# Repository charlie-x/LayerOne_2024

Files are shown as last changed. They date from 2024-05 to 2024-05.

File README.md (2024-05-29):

# LayerOne_2024
Repo for LayerOne 2024

# L1 Pov Spinner

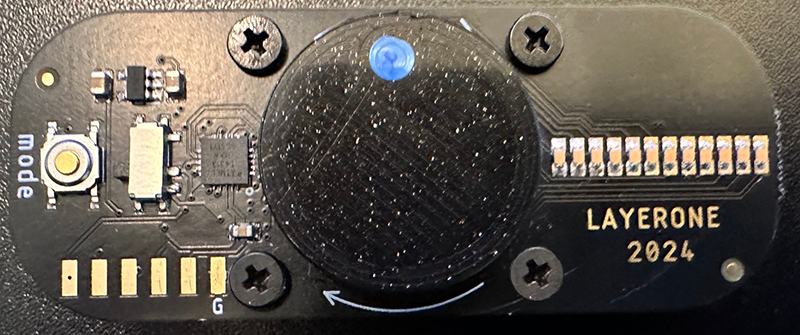
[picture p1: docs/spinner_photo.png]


## What is the Pov Spinner?

The Pov Spinner is an electronic fidget spinner that displays words and patterns via LED's when spinning. It was part of the LayerOne 2024 Conference badge.

## What is needed to change the code on the Spinner?

* Code from repo
* Computer
* AVR programming device
* Build software
* Flash software
* Device drivers

# Code from repo

Clone the git repo or download the zip of the repo

## git clone
```
git clone https://github.com/charlie-x/LayerOne_2024.git
```

## Download zip

```
wget https://github.com/charlie-x/LayerOne_2024/archive/refs/heads/main.zip
```

## Edit the code

Open the **L12024POV.cproj** project file.

The text and animation code is located in **main.c**.

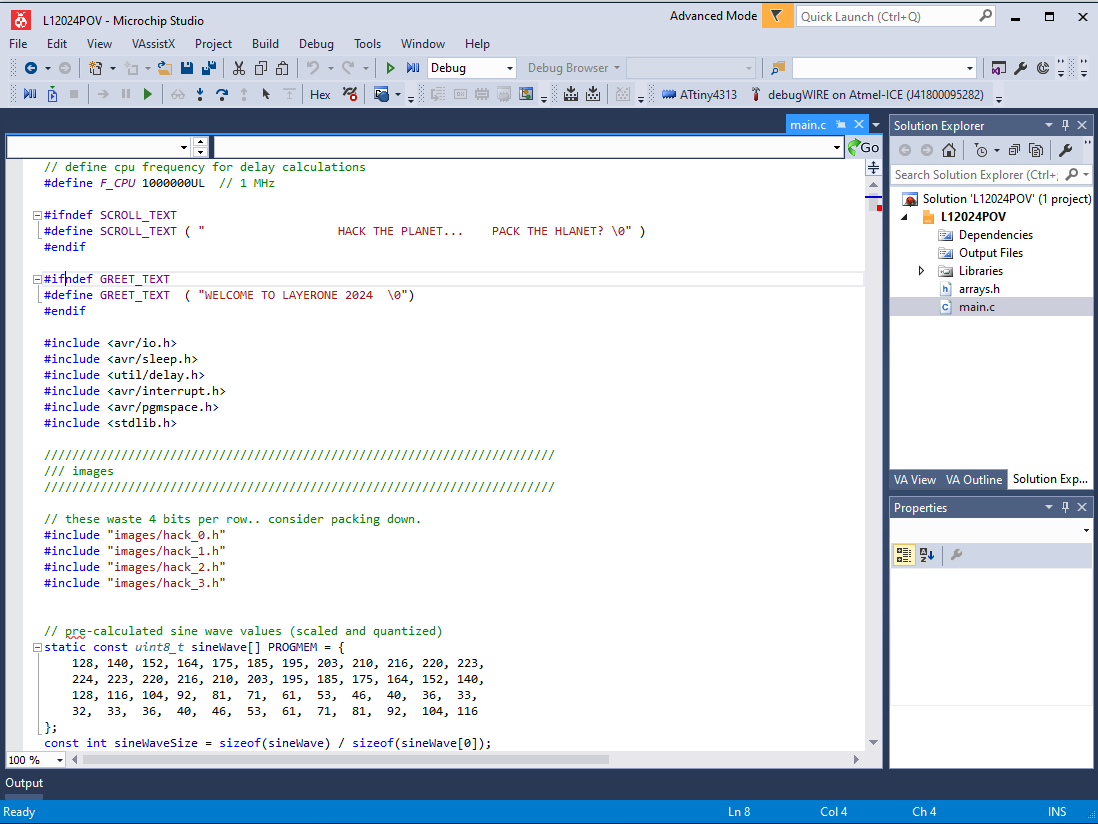
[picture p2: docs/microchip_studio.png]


Once the desired changes are complete, run the **build**. This will output the build files into the **Debug** folder.  

The **L12024POV.hex** file created is what will be used to flash the spinner.

## AVR programing device

**NOTE: Any AVR programmer should work.**

The LayerOne attendees were able to obtain a **Kraken** AVR programmer to use for this purpose which is an avrisp/mkii/avr dragon/usbasp.

Kraken based on this board: 

https://www.fischl.de/usbasp/

### Arduino as an AVR programmer

Alternatively, and Ardunio can be used to program the device:

https://docs.arduino.cc/built-in-examples/arduino-isp/ArduinoISP/

https://www.amazon.com/CANADUINO-USBtinyISP-Programmer-Compatible-Arduino/dp/B0751LJH3Z

## Build Software

Either use Microchip Studio or avr-gcc to build it.

### *nix

Install **avr-gcc** via the **gcc-avr** package

sudo apt-get install binutils gcc-avr avr-libc uisp avrdude flex byacc bison

### Windows

https://www.microchip.com/en-us/tools-resources/develop/microchip-studio

### Mac

port

https://ports.macports.org/port/avr-gcc/

homebrew

https://github.com/osx-cross/homebrew-avr

for avr-gcc's use the makefile

## Flashing the board

**NOTE: The kraken needs avrdude, it is not supported in microchip studio.**

### *nix / Windows / Mac - avrdude

AVRDUDE - is a program for downloading and uploading the on-chip memories of Microchip’s AVR microcontrollers.

Flash the board with the compiled **hex** file to device

https://github.com/avrdudes/avrdude/releases

```
avrdude -c usbasp -p t4313 -v -B 3 -U flash:w:..\LayerOne_2024-main\LayerOne_2024-main\L1_POVSpinner\L12024POV\Debug\L12024POV.hex
```

### Windows - atprogram

atprogram - is a program that comes with Microchip Studio

```
atprogram -cl 200khz -v -d attiny4313 -t atmelice -i isp chiperase
atprogram -cl 200khz -v -d attiny4313 -t atmelice -i isp program -f L12024POV\Release\L12024POV.elf
```

#### Device Drivers for Windows

Zadig is a Windows application that installs generic USB drivers, such as WinUSB, libusb-win32/libusb0.sys or libusbK, to help you access USB devices that can be found here:
https://zadig.akeo.ie/#

Install the **libusbK** driver

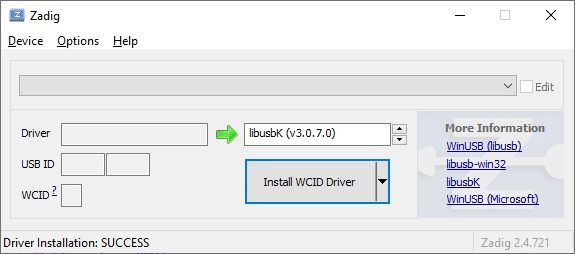
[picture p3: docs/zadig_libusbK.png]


## Spinner Pinouts for programming

The device has the Ground pin labeld as **G**. 

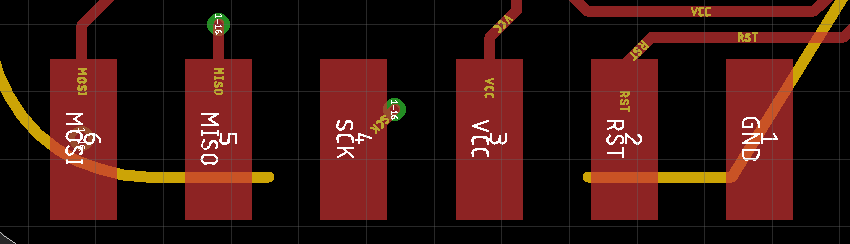
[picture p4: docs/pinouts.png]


## Notes on modifiying the code

The image folder are made of 12xN high 1 bit png's and the imageConvert tool spits them out as a header file, just include them and use drawImage

imageConvert <in.png> <out.h> <label>

use <label> to pass into drawImage use #include <out.h> (with the right name) in the main.c

interrupt driven from a hall effect sensor, triggers the loops to draw and calcs an RPM then it goes into sleep after the effect is drawn, the hall effect can wake it up, but to save battery pressing the button wakes the cpu up again

the slider switch needs to be be in the furthest away position from the programming pads, match the G to gnd on the programmer..

==============================================================================

calculate x/y

30 is 360/nuber of leds around, which is speed dependant  so used the number of leds vertically

  angle_radians = ( led_number * 30 *pi / 180  )

  x_inner = radius * cos ( angle_radius )
  y_inner = radius * cos ( angle_radius )

distance...

  distance = sqrt( (dx^2) + (dy^2))

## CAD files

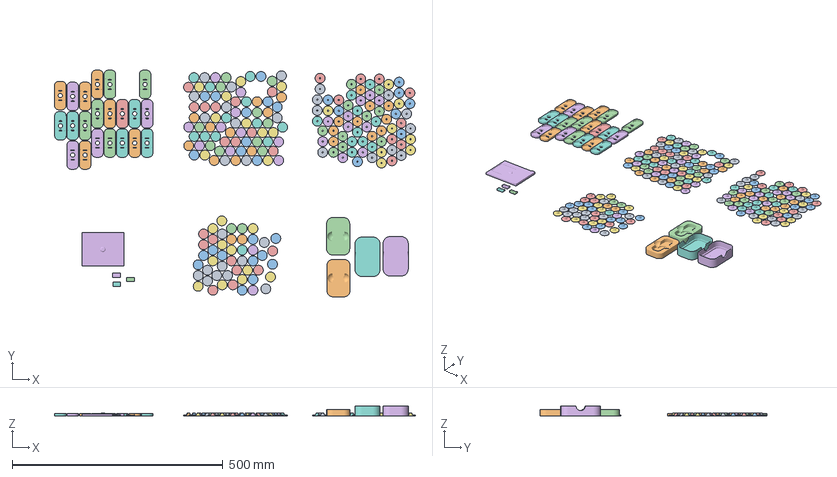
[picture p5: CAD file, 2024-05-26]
L1_2024_PROD_Spinner_Sparkle.3mf
856.6 x 537.8 x 24.2 mm
spin_pov_case_LAYERONE v11 bottom.step
L1_spin_carry_case v3 bottom.step x 2
spin_mag_L1 v8 LOGO.step x 48
spin_pov_case_LAYERONE v11 bottom.step 1
L1_spin_carry_case v4 top.step x 2
spin_pov_case_LAYERONE v11 bottom.step 2
spin_pov_case_LAYERONE v11 bottom.step 3
spin_pov_case_LAYERONE v11 bottom.step 4
spin_pov_case_LAYERONE v11 bottom.step 5
spin_pov_case_LAYERONE v11 bottom.step 6
spin_pov_case_LAYERONE v11 bottom.step 7
spin_pov_case_LAYERONE v11 25.step
spin_pov_case_LAYERONE v11 bottom.step 8
spin_pov_case_LAYERONE v11 bottom.step 9
spin_pov_case_LAYERONE v11 bottom.step 10
spin_pov_case_LAYERONE v11 bottom.step 11
spin_pov_case_LAYERONE v11 bottom.step 12
spin_pov_case_LAYERONE v11 bottom.step 13
spin_pov_case_LAYERONE v11 bottom.step 14
spin_pov_case_LAYERONE v11 bottom.step 15
spin_pov_case_LAYERONE v11 bottom.step 16
spin_pov_case_LAYERONE v11 bottom.step 17
spin_pov_case_LAYERONE v11 bottom.step 18
spin_pov_case_LAYERONE v11 bottom.step 19
spin_pov_case_LAYERONE v11 bottom.step 20
spin_pov_case_LAYERONE v11 bottom.step 21
spin_pov_case_LAYERONE v11 bottom.step 22
spin_pov_case_LAYERONE v11 bottom.step 23
spin_pov_case_LAYERONE v11 bottom.step 24
spin_pov_case_LAYERONE v11 bottom.step 25
spin_pov_case_LAYERONE v11 bottom.step 26
spin_pov_case_LAYERONE v11 bottom.step 27
spin_pov_case_LAYERONE v11 bottom.step 28
spin_pov_case_LAYERONE v11 bottom.step 29
spin_pov_case_LAYERONE v11 bottom.step 30
spin_pov_case_LAYERONE v11 bottom.step 31
spin_pov_case_LAYERONE v11 bottom.step 32
spin_pov_case_LAYERONE v11 bottom.step 33
spin_pov_case_LAYERONE v11 bottom.step 34
spin_pov_case_LAYERONE v11 bottom.step 35
spin_pov_case_LAYERONE v11 bottom.step 36
spin_pov_case_LAYERONE v11 bottom.step 37
spin_pov_case_LAYERONE v11 bottom.step 38
spin_pov_case_LAYERONE v11 bottom.step 39
spin_pov_case_LAYERONE v11 bottom.step 40
spin_pov_case_LAYERONE v11 bottom.step 41
spin_pov_case_LAYERONE v11 bottom.step 42
spin_pov_case_LAYERONE v11 bottom.step 43
spin_pov_case_LAYERONE v11 bottom.step 44
spin_pov_case_LAYERONE v11 bottom.step 45
spin_pov_case_LAYERONE v11 bottom.step 46
spin_pov_case_LAYERONE v11 bottom.step 47
spin_pov_case_LAYERONE v11 bottom.step 48
spin_pov_case_LAYERONE v11 bottom.step 49
spin_pov_case_LAYERONE v11 25.step 1
spin_pov_case_LAYERONE v11 bottom.step 50
spin_pov_case_LAYERONE v11 25.step 2
spin_pov_case_LAYERONE v11 bottom.step 51
spin_pov_case_LAYERONE v11 25.step 3
spin_pov_case_LAYERONE v11 bottom.step 52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

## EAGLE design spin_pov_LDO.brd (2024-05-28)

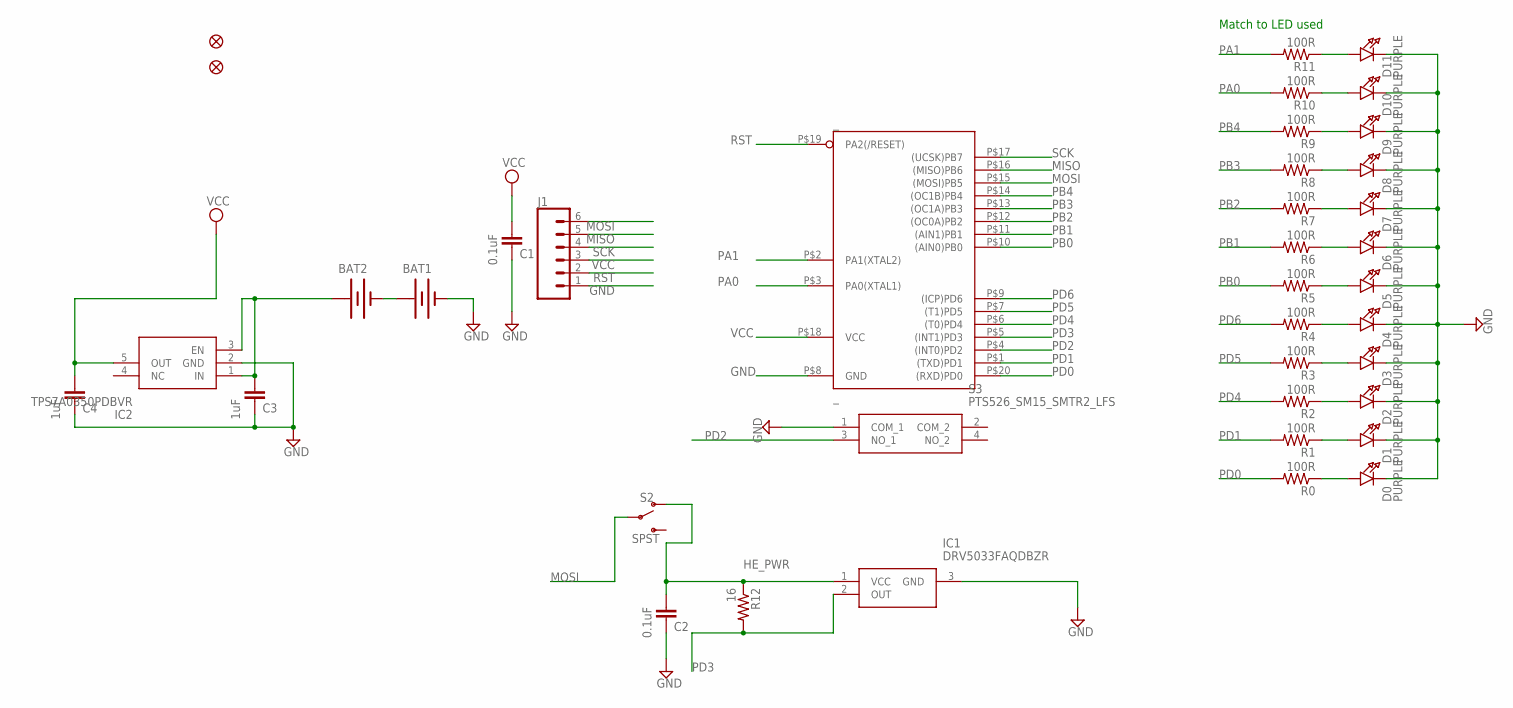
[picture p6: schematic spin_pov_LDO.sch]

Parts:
AFID1, AFID2: FIDUCIAL""; FIDUCIAL_1MM
BAT1, BAT2: SPARKFUN_BATTERYSPARKFUN_BATTCOMM_20MM_LINX; SPARKFUN_BATTCOM_20MM_LINX
C1, C2: 0.1uF; 0805
C3, C4: 1uF; 0805
D0, D1, D2, D3, D4, D5, D6, D7, D8, D9, D10, D11: PURPLE; CHIPLED_0805_NOOUTLINE
IC1: DRV5033FAQDBZR; SOT95P237X112-3N
IC2: TPS7A0350PDBVR; SOT95P280X145-5N
J1: CONN_06SMD-FEMALE-V2; 1X06-SMD-FEMALE
R0, R1, R2, R3, R4, R5, R6, R7, R8, R9, R10, R11: 100R; 0805
R12: 16; 0805
S2: SPST; SWITCH_SPST_SMD_A
S3: PTS526_SM15_SMTR2_LFS; PTS526SM15SMTR2LFS
_: _; MLF20

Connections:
GND: BAT1.2 (-), C1.2, C2.2, C3.2, C4.2, D0.C, D1.C, D2.C, D3.C, D4.C, D5.C, D6.C, D7.C, D8.C, D9.C, D10.C, D11.C, IC1.3 (GND), IC2.2 (GND), J1.1, S3.1 (COM_1), _.P$8 (GND)
HE_PWR: C2.1, IC1.1 (VCC), R12.1, S2.1 (O)
MISO: J1.5, _.P$16 ((MISO)PB6)
MOSI: J1.6, S2.2, _.P$15 ((MOSI)PB5)
unnamed: BAT2.1 (+), C3.1, IC2.1 (IN), IC2.3 (EN)
unnamed: BAT1.1 (+), BAT2.2 (-)
unnamed: D0.A, R0.1
unnamed: D1.A, R1.1
unnamed: D2.A, R2.1
unnamed: D3.A, R3.1
unnamed: D4.A, R4.1
unnamed: D5.A, R5.1
unnamed: D6.A, R6.1
unnamed: D7.A, R7.1
unnamed: D8.A, R8.1
unnamed: D9.A, R9.1
unnamed: D10.A, R10.1
unnamed: D11.A, R11.1
PA0: R10.2, _.P$3 (PA0(XTAL1))
PA1: R11.2, _.P$2 (PA1(XTAL2))
PB0: R5.2, _.P$10 ((AIN0)PB0)
PB1: R6.2, _.P$11 ((AIN1)PB1)
PB2: R7.2, _.P$12 ((OC0A)PB2)
PB3: R8.2, _.P$13 ((OC1A)PB3)
PB4: R9.2, _.P$14 ((OC1B)PB4)
PD0: R0.2, _.P$20 ((RXD)PD0)
PD1: R1.2, _.P$1 ((TXD)PD1)
PD2: S3.3 (NO_1), _.P$4 ((INT0)PD2)
PD3: IC1.2 (OUT), R12.2, _.P$5 ((INT1)PD3)
PD4: R2.2, _.P$6 ((T0)PD4)
PD5: R3.2, _.P$7 ((T1)PD5)
PD6: R4.2, _.P$9 ((ICP)PD6)
RST: J1.2, _.P$19 (PA2(/RESET))
SCK: J1.4, _.P$17 ((UCSK)PB7)
VCC: C1.1, C4.1, IC2.5 (OUT), J1.3, _.P$18 (VCC)

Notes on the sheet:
Match to LED used

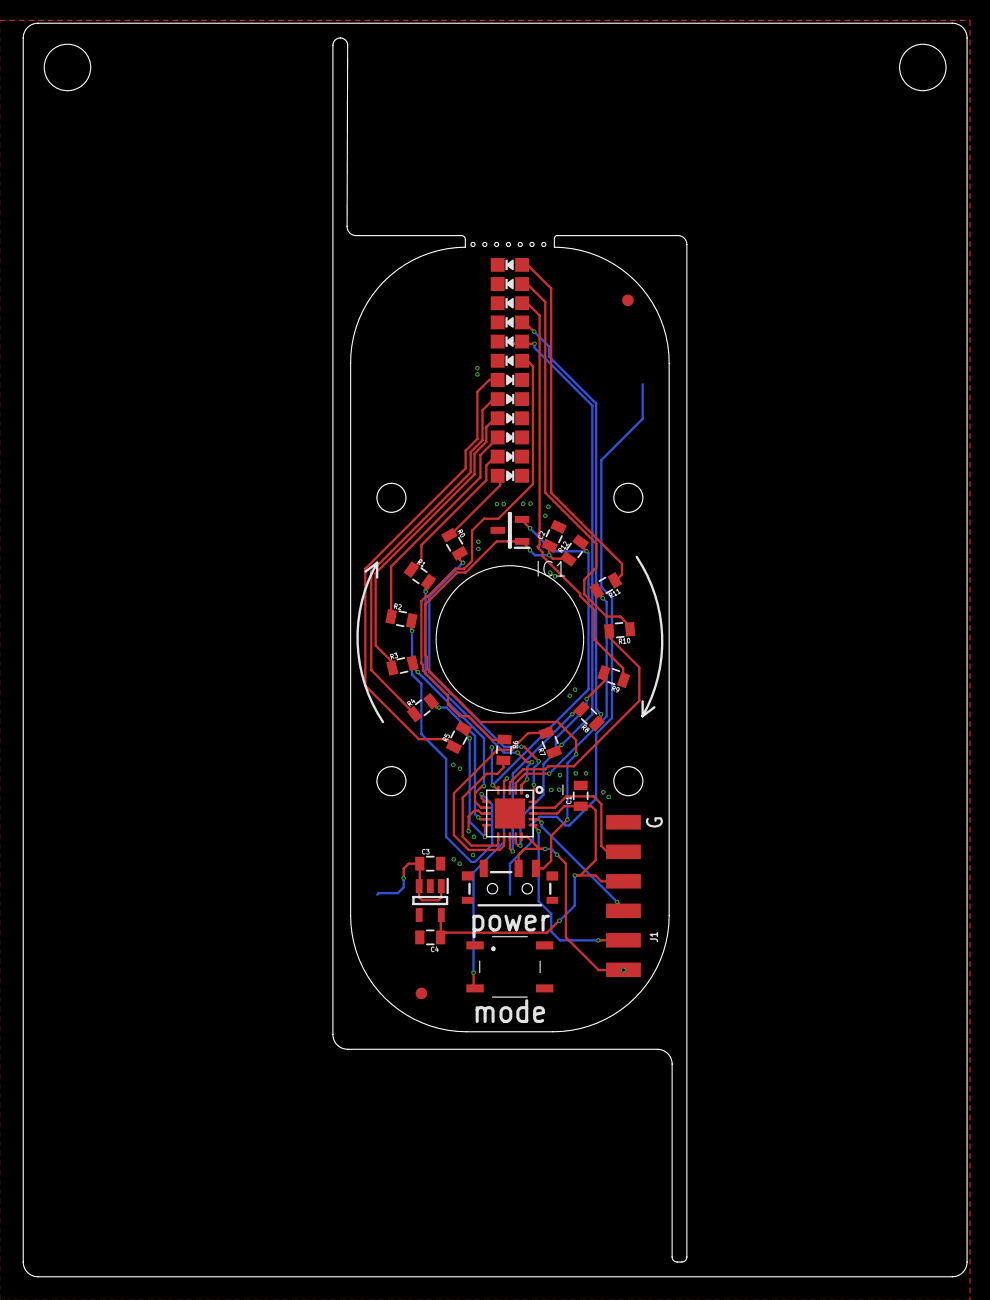
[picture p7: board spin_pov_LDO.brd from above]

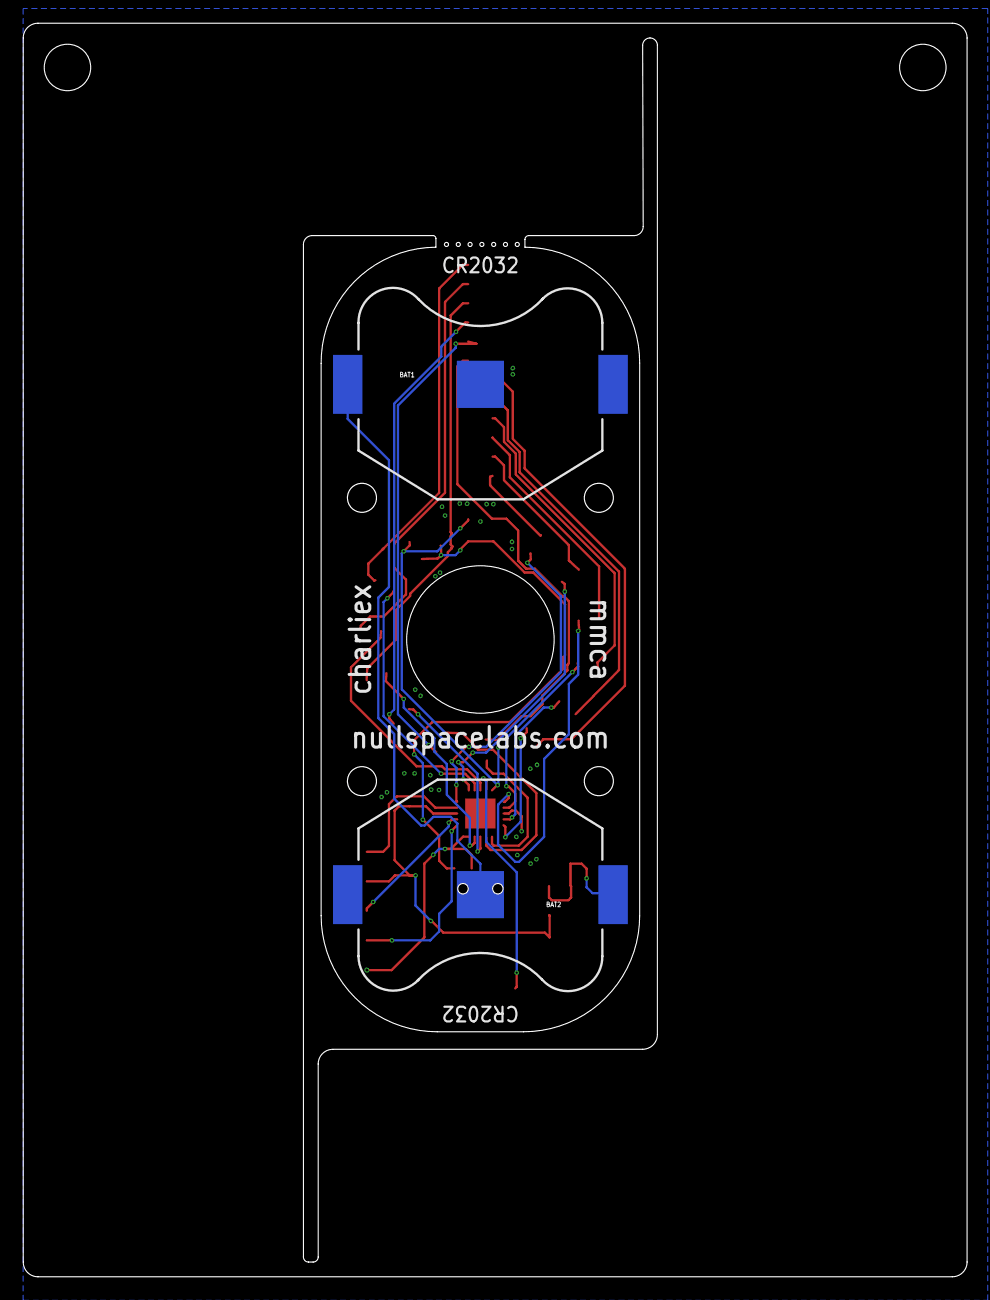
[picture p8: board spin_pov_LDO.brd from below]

Board: 2 copper layers, 81.3 x 107.9 mm, 39 parts (2 on the bottom side), 35 nets.

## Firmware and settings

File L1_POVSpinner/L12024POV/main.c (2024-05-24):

// define cpu frequency for delay calculations
#define F_CPU 1000000UL  // 1 MHz

#ifndef SCROLL_TEXT
#define SCROLL_TEXT ( "                   HACK THE PLANET...    PACK THE HLANET? \0" )
#endif

#ifndef GREET_TEXT
#define GREET_TEXT  ( "WELCOME TO LAYERONE 2024  \0")
#endif

#include <avr/io.h>
#include <avr/sleep.h>
#include <util/delay.h>
#include <avr/interrupt.h>
#include <avr/pgmspace.h>
#include <stdlib.h>

/////////////////////////////////////////////////////////////////////////
/// images
/////////////////////////////////////////////////////////////////////////

// these waste 4 bits per row.. consider packing down.
#include "images/hack_0.h"
#include "images/hack_1.h"
#include "images/hack_2.h"
#include "images/hack_3.h"


// pre-calculated sine wave values (scaled and quantized)
static const uint8_t sineWave[] PROGMEM = {
	128, 140, 152, 164, 175, 185, 195, 203, 210, 216, 220, 223,
	224, 223, 220, 216, 210, 203, 195, 185, 175, 164, 152, 140,
	128, 116, 104, 92,  81,  71,  61,  53,  46,  40,  36,  33,
	32,  33,  36,  40,  46,  53,  61,  71,  81,  92,  104, 116
};
const int sineWaveSize = sizeof(sineWave) / sizeof(sineWave[0]);

/////////////////////////////////////////////////////////////////////////
/// fonts
/////////////////////////////////////////////////////////////////////////


static const uint8_t fontMap[][8] PROGMEM = {

	// Numbers 0-9
	{
		0b00111110, 0b01010001, 0b01001001, 0b01000101, 0b00111110, 0b00000000, 0b00000000, 0b00000000
	}, // 0
	{
		0b00000000, 0b01000010, 0b01111111, 0b01000000, 0b00000000, 0b00000000, 0b00000000, 0b00000000
	}, // 1
	{
		0b01000010, 0b01100001, 0b01010001, 0b01001001, 0b01000110, 0b00000000, 0b00000000, 0b00000000
	}, // 2
	{
		0b00100001,
		0b01000001,
		0b01000101,
		0b01001011,
		0b00110001,
		0b00000000,
		0b00000000,
		0b00000000
	}, // 3
	{
		0b00011000,
		0b00010100,
		0b00010010,
		0b01111111,
		0b00010000,
		0b00000000,
		0b00000000,
		0b00000000
	}, // 4
	{
		0b00100111, 0b01000101, 0b01000101, 0b01000101, 0b00111001, 0b00000000, 0b00000000, 0b00000000
	}, // 5
	{
		0b00111100, 0b01001010, 0b01001001, 0b01001001, 0b00110000, 0b00000000, 0b00000000, 0b00000000
	}, // 6
	{
		0b00000001, 0b01110001, 0b00001001, 0b00000101, 0b00000011, 0b00000000, 0b00000000, 0b00000000
	}, // 7
	{
		0b00110110, 0b01001001, 0b01001001, 0b01001001, 0b00110110, 0b00000000, 0b00000000, 0b00000000
	}, // 8
	{
		0b00000110, 0b01001001, 0b01001001, 0b00101001, 0b00011110, 0b00000000, 0b00000000, 0b00000000
	} ,// 9


	{
		0b01111110, 0b00010001, 0b00010001, 0b00010001, 0b01111110, 0b00000000
	}, // A
	{
		0b01111111, 0b01001001, 0b01001001, 0b01001001, 0b00110110, 0b00000000
	}, // B
	{
		0b00111110, 0b01000001, 0b01000001, 0b01000001, 0b00100010, 0b00000000
	}, // C
	{
		0b01111111, 0b01000001, 0b01000001, 0b01000001, 0b00111110, 0b00000000
	}, // D
	{
		0b01111111, 0b01001001, 0b01001001, 0b01001001, 0b01000001, 0b00000000
	}, // E
	{
		0b01111111, 0b00001001, 0b00001001, 0b00001001, 0b00000001, 0b00000000
	}, // F
	{
		0b00111110, 0b01000001, 0b01001001, 0b01001001, 0b01111010, 0b00000000
	}, // G
	{
		0b01111111, 0b00001000, 0b00001000, 0b00001000, 0b01111111, 0b00000000
	}, // H
	{
		0b00000000, 0b01000001, 0b01111111, 0b01000001, 0b00000000, 0b00000000
	}, // I
	{
		0b00100000, 0b01000000, 0b01000001, 0b00111111, 0b00000001, 0b00000000
	}, // J
	{
		0b01111111, 0b00001000, 0b00010100, 0b00100010, 0b01000001, 0b00000000
	}, // K
	{
		0b01111111, 0b01000000, 0b01000000, 0b01000000, 0b01000000, 0b00000000
	}, // L
	{
		0b01111111, 0b00000010, 0b00001100, 0b00000010, 0b01111111, 0b00000000
	}, // M
	{
		0b01111111, 0b00000100, 0b00001000, 0b00010000, 0b01111111, 0b00000000
	}, // N
	{
		0b00111110, 0b01000001, 0b01000001, 0b01000001, 0b00111110, 0b00000000
	}, // O
	{
		0b01111111, 0b00001001, 0b00001001, 0b00001001, 0b00000110, 0b00000000
	}, // P
	{
		0b00111110, 0b01000001, 0b01010001, 0b00100001, 0b01011110, 0b00000000
	}, // Q
	{
		0b01111111, 0b00001001, 0b00011001, 0b00101001, 0b01000110, 0b00000000
	}, // R
	{
		0b01000110, 0b01001001, 0b01001001, 0b01001001, 0b00110001, 0b00000000
	}, // S
	{
		0b00000001, 0b00000001, 0b01111111, 0b00000001, 0b00000001, 0b00000000
	}, // T
	{
		0b00111111, 0b01000000, 0b01000000, 0b01000000, 0b00111111, 0b00000000
	}, // U
	{
		0b00011111, 0b00100000, 0b01000000, 0b00100000, 0b00011111, 0b00000000
	}, // V
	{
		0b00111111, 0b01000000, 0b00111000, 0b01000000, 0b00111111, 0b00000000
	}, // W
	{
		0b01100011, 0b00010100, 0b00001000, 0b00010100, 0b01100011, 0b00000000
	}, // X
	{
		0b00000111, 0b00001000, 0b01110000, 0b00001000, 0b00000111, 0b00000000
	}, // Y
	{
		0b01100001, 0b01010001, 0b01001001, 0b01000101, 0b01000011, 0b00000000
	} // Z

};


// define led pins
#define LED_PORT					PORTA
#define LED_DDR						DDRA

#define BUTTON						PD2
#define HALL_EFFECT_POWER			PB5

#define BIT_SET(port, bit)			((port) |= (1 << (bit)))
#define BIT_CLEAR(port, bit)		((port) &= ~(1 << (bit)))
#define BIT_TEST(port, bit)			((port) & (1 << (bit)))

// SLEEP_MODE_PWR_DOWN
// SLEEP_MODE_STANDBY
// SLEEP_MODE_IDLE

#define SLEEP_MODE					SLEEP_MODE_PWR_DOWN

#define true						( 1 )
#define false						( 0 )

// set to actual effects + 1
#define MAX_EFFECTS					( 10 )

// main loop delay ms*COUNTDOWN_LENGTH
#define COUNTDOWN_LENGTH			( 50000 )


// set the delay we're using
#define _delay_adaptive(x) { customDelayMicroseconds((delayAdj));}


void drawNumber(uint16_t num);
void setLEDS( uint16_t mask );

/////////////////////////////////////////////////////////////////////////
/// handling rpm
/////////////////////////////////////////////////////////////////////////


// out here for debugging mostly
volatile uint16_t lastTimerValue = 0;
volatile uint16_t rpmValue = 0;
volatile uint32_t revolutionDurationMs = 0;
uint16_t currentTimerValue;

// effects count
uint8_t count = 0;


// how much to delay by
volatile uint32_t delayAdj = 0;

// internal counter for timers
volatile uint32_t totalTimerTicks = 0;

// used for toggling animations etc
volatile uint8_t fillModeEffects = 0;

// effect index to display
volatile uint8_t currentEffect = 7;

// for knowing if we were just asleep
volatile uint8_t isSleeping = false;

// software counter for powering down delay
volatile uint32_t powerDownCountdown = COUNTDOWN_LENGTH;

// did we just hit the hall effect
volatile uint8_t  isTriggered = false;

// read the button
// 1 if pressed, 0 if not
uint8_t readButton() {
	return ((PIND & (1 << BUTTON)) == 0);
}


// arduino delay code
/* Delay for the given number of microseconds.  Assumes a 1, 8, 12, 16, 20 or 24 MHz clock. */
void customDelayMicroseconds(unsigned int us)
{

	// call = 4 cycles + 2 to 4 cycles to init us(2 for constant delay, 4 for variable)

	// calling avrlib's delay_us() function with low values (e.g. 1 or
	// 2 microseconds) gives delays longer than desired.
	//delay_us(us);
	#if F_CPU >= 24000000L
	// for the 24 MHz clock for the adventurous ones, trying to overclock

	// zero delay fix
	if (!us) return; //  = 3 cycles, (4 when true)

	// the following loop takes a 1/6 of a microsecond (4 cycles)
	// per iteration, so execute it six times for each microsecond of
	// delay requested.
	us *= 6; // x6 us, = 7 cycles

	// account for the time taken in the preceding commands.
	// we just burned 22 (24) cycles above, remove 5, (5*4=20)
	// us is at least 6 so we can subtract 5
	us -= 5; //=2 cycles

	#elif F_CPU >= 20000000L
	// for the 20 MHz clock on rare Arduino boards

	// for a one-microsecond delay, simply return.  the overhead
	// of the function call takes 18 (20) cycles, which is 1us
	__asm__ __volatile__ (
	"nop" "\n\t"
	"nop" "\n\t"
	"nop" "\n\t"
	"nop"); //just waiting 4 cycles
	if (us <= 1) return; //  = 3 cycles, (4 when true)

	// the following loop takes a 1/5 of a microsecond (4 cycles)
	// per iteration, so execute it five times for each microsecond of
	// delay requested.
	us = (us << 2) + us; // x5 us, = 7 cycles

	// account for the time taken in the preceding commands.
	// we just burned 26 (28) cycles above, remove 7, (7*4=28)
	// us is at least 10 so we can subtract 7
	us -= 7; // 2 cycles

	#elif F_CPU >= 16000000L
	// for the 16 MHz clock on most Arduino boards

	// for a one-microsecond delay, simply return.  the overhead
	// of the function call takes 14 (16) cycles, which is 1us
	if (us <= 1) return; //  = 3 cycles, (4 when true)

	// the following loop takes 1/4 of a microsecond (4 cycles)
	// per iteration, so execute it four times for each microsecond of
	// delay requested.
	us <<= 2; // x4 us, = 4 cycles

	// account for the time taken in the preceding commands.
	// we just burned 19 (21) cycles above, remove 5, (5*4=20)
	// us is at least 8 so we can subtract 5
	us -= 5; // = 2 cycles,

	#elif F_CPU >= 12000000L
	// for the 12 MHz clock if somebody is working with USB

	// for a 1 microsecond delay, simply return.  the overhead
	// of the function call takes 14 (16) cycles, which is 1.5us
	if (us <= 1) return; //  = 3 cycles, (4 when true)

	// the following loop takes 1/3 of a microsecond (4 cycles)
	// per iteration, so execute it three times for each microsecond of
	// delay requested.
	us = (us << 1) + us; // x3 us, = 5 cycles

	// account for the time taken in the preceding commands.
	// we just burned 20 (22) cycles above, remove 5, (5*4=20)
	// us is at least 6 so we can subtract 5
	us -= 5; //2 cycles

	#elif F_CPU >= 8000000L
	// for the 8 MHz internal clock

	// for a 1 and 2 microsecond delay, simply return.  the overhead
	// of the function call takes 14 (16) cycles, which is 2us
	if (us <= 2) return; //  = 3 cycles, (4 when true)

	// the following loop takes 1/2 of a microsecond (4 cycles)
	// per iteration, so execute it twice for each microsecond of
	// delay requested.
	us <<= 1; //x2 us, = 2 cycles

	// account for the time taken in the preceding commands.
	// we just burned 17 (19) cycles above, remove 4, (4*4=16)
	// us is at least 6 so we can subtract 4
	us -= 4; // = 2 cycles

	#else
	// for the 1 MHz internal clock (default settings for common Atmega micro controllers)

	// the overhead of the function calls is 14 (16) cycles
	if (us <= 16) return; //= 3 cycles, (4 when true)
	if (us <= 25) return; //= 3 cycles, (4 when true), (must be at least 25 if we want to subtract 22)

	// compensate for the time taken by the preceding and next commands (about 22 cycles)
	us -= 22; // = 2 cycles
	// the following loop takes 4 microseconds (4 cycles)
	// per iteration, so execute it us/4 times
	// us is at least 4, divided by 4 gives us 1 (no zero delay bug)
	us >>= 2; // us div 4, = 4 cycles
	

	#endif

	// busy wait
	__asm__ __volatile__ (
	"1: sbiw %0,1" "\n\t" // 2 cycles
	"brne 1b" : "=w" (us) : "0" (us) // 2 cycles
	);
	// return = 4 cycles
}

// calculate delay time for 1 degree of rotation based on RPM
float calculateMSDelayPerDegree(uint32_t rpm) {
	if (rpm == 0) {
		return 100;														// avoid division by zero
	}

	float  timePerRevolutionSeconds = 60.0f / rpm;						// time per revolution in seconds
	float delayPerDegreeSeconds = timePerRevolutionSeconds / 360.0f;	// time for 1 degree in seconds

	return (uint32_t) ((float)delayPerDegreeSeconds * 1000.0f);			// convert to milliseconds
}

// calculate the adjustable delay based on RPM
uint32_t calculateAdjustableDelay() {
	
	//if (rpm == 0) return 500;  // Max delay to prevent operation halt

	return (revolutionDurationMs / 128)*4;
}

// figure out RPM

// calculate RPM from time per revolution in milliseconds
uint32_t calculateRPM() {
	if (revolutionDurationMs == 0) {
		return 0; // Avoid division by zero
	}

	return (uint32_t) ((float)(600000.0f / revolutionDurationMs));
}

//draw a single glyph
void drawDigitR(uint8_t num) {

	for (uint8_t row = 0; row < 8; row++) {
		setLEDS( pgm_read_byte( &fontMap[num][row]) );
		_delay_adaptive(500);
	}
}


// draw a single char, 0-9 A-Z
void drawChar(uint8_t c) {
	if (c >= '0' && c <= '9') {
		drawDigitR(c - '0');
		} else if (c >= 'A' && c <= 'Z') {
		drawDigitR(c - 'A' + 10);
		// delay for space
		}else if( c == ' ')  {
		_delay_us(500);
	}
}

// expensive.. draw a 16 bit decimal number
void drawNumber(uint16_t num) {
	drawDigitR(num / 1000);							// thousands
	_delay_adaptive(100);
	drawDigitR((num / 100) - (num / 1000) * 10);	// hundreds
	_delay_adaptive(100);
	drawDigitR((num / 10) - (num / 100) * 10);		// tens
	_delay_adaptive(100);
	drawDigitR(num - (num / 10) * 10);				// ones
	_delay_adaptive(100);
}

// draw a single glyph with scroll offset
// @param num Glyph number to draw
// @param offset Pixel offset for scrolling
void drawDigitScrollable(uint8_t num, int8_t offset) {
	for (uint8_t row = 0; row < 8; row++) {
		uint8_t rowData = pgm_read_byte(&fontMap[num][row]);
		// Apply scroll offset
		if (offset > 0) {
			rowData <<= offset; // Scroll left
			} else if (offset < 0) {
			rowData >>= -offset; // Scroll right
		}
		setLEDS(rowData);
		_delay_adaptive(500);
	}
}

// drawChar to include scroll offset
// @param c Character to draw
// @param offset Pixel offset for scrolling
void drawCharScrollable(uint8_t c, int8_t offset) {
	if (c >= '0' && c <= '9') {
		drawDigitScrollable(c - '0', offset);
		} else if (c >= 'A' && c <= 'Z') {
		drawDigitScrollable(c - 'A' + 10, offset);
		} else if (c == ' ') {
		_delay_us(500); // Delay for space, consider scrolling space if needed
	}
}

// drawString to include vertically scroll 
// @param str Pointer to the string to be drawn
// @param offset Pixel offset for scrolling
void drawStringScrollableV(const char* str, int8_t offset) {
	while (*str) {
		drawCharScrollable(*str++, offset);
		_delay_adaptive(100); // delay between characters for readability
	}
}

// draw a string
void drawString(const char* str) {
	while (*str) {
		drawChar(*str++);
		_delay_adaptive(100);  // delay between characters for readability
	}
}



// Draw a single glyph with horizontal scroll offset for a POV spinner
// @param num Glyph number to draw
// @param column Column of the glyph to display for horizontal scrolling
void drawDigitPOV(uint8_t num, uint8_t column) {
	// Assuming 8 LEDs in vertical array and 8 bits per glyph row
	for (uint8_t row = 0; row < 8; row++) {
		uint8_t rowData = pgm_read_byte(&fontMap[num][row]);
		
		// Extract the bit for the current column
		uint8_t columnData = (rowData >> (7 - column)) & 0x01;
		
		// Convert columnData to vertical LED pattern
		uint16_t ledPattern = columnData ? (1 << row) : 0;
		
		setLEDS(ledPattern);
		
		// Adjust delay for POV display timing
		_delay_adaptive(50); // This delay might need tuning based on actual POV speed
	}
}

// Modified drawChar to handle POV horizontal scrolling
// @param c Character to draw
// @param column Column of the character to display for scrolling
void drawCharPOV(uint8_t c, uint8_t column) {
	if (c >= '0' && c <= '9') {
		drawDigitPOV(c - '0', column);
		} else if (c >= 'A' && c <= 'Z') {
		drawDigitPOV(c - 'A' + 10, column);
		} else if (c == ' ') {
		// Handle space character for POV display
		setLEDS(0); // Clear LEDs for space
		_delay_adaptive(50); // Maintain timing consistency
	}
}

// Function to scroll a string horizontally on a POV display
// @param str Pointer to the string to be scrolled
void scrollStringPOV(const char* str)
{
	static uint8_t column = 0;
	const char *rstr = str;
	
	// add on offset to string
	str+=column;
	
	// if hit the end of the string, reset it back it the start, add a visible delay and go back to outer loop
	if( *str == 0 ) {
			
		str = rstr;
		column=0;
			
		_delay_adaptive(500); // Maintain timing consistency
		return; //otherwise it will loop forever
	}
	
	// the outside main loop counter for the effects
//	if (count == 1 ) {
//		column++;
//	}
	
	column++;
	uint8_t chars = 0;
	while (*str) {
		// For each character, scroll through its columns
		{
			if(*str == '@' ) {
				_delay_adaptive(500);  // delay between characters for readability 
			} else {
				drawChar(*str);
			
				_delay_adaptive(100);  // delay between characters for readability
				}
			chars++;
			
			// don't wrap over the start, adjust this for length of text drawn at once
			if( chars == 15 ) break;

			
		}
		
		str++; // Move to next character
		
	
	}
}

// draw an image from an array
// The array should have 8 pairs of uint8_t values, each pair representing 12 bits (for 12 LEDs)
void drawImage(const uint16_t image_data[],uint8_t height)
{
	for (uint8_t row = 0; row < height; ++row) {
		
		uint16_t rowData =pgm_read_word( &image_data[row]);
		
		// call setLEDs to display this row
		setLEDS(rowData);

		// delay for persistence of vision
		_delay_adaptive(5700);
	}
}

/////////////////////////////////////////////////////////////////////////
/// effects
/////////////////////////////////////////////////////////////////////////

void sineWaveEffect(uint8_t mode ) {
	static int waveIndex = 0;
	const int numLEDs = 12;
	uint16_t ledValue = 0;
	const uint8_t threshold = 128; // Mid-point of the scaled sine wave

	
	for(uint8_t i = 0 ; i < 250; i++)
	{
		
		if(readButton())break;
		
		ledValue = 0;

		for (int i = 0; i < numLEDs; i++) {
			int index = (waveIndex + i) % sineWaveSize;
			if (pgm_read_byte( &sineWave[index] ) > threshold) {
				ledValue |= (1 << i);
				if( mode) {
					setLEDS(ledValue);
					for( uint16_t o = 0; o  <delayAdj/4  ; o++ )
					_delay_us(1);
				}
			}
		}

		if( !mode)
		setLEDS(ledValue);

		waveIndex++;
		
		if (waveIndex >= sineWaveSize) {
			waveIndex = 0;
		}

		// Simple delay
		//customDelayMicroseconds(delayAdj/4);
		//_delay_adaptive(800); // Adjust the delay as needed
		
		//i++;
		//if( i>=250) i =0;
	}
}

/////////////////////////////////////////////////////////////////////////
/// timer
/////////////////////////////////////////////////////////////////////////

void setupTimer() {
	// configure Timer1
	TCCR1B |= (1 << CS11);			// 8 prescaler
	TCNT1 = 0;
}

// set the leds.
void setLEDS( uint16_t mask )
{

	#define inv  (11)
	
	if (BIT_TEST(mask,inv -  0) ) BIT_SET( PORTD, PD0) ; else BIT_CLEAR (PORTD , PD0);
	if (BIT_TEST(mask,inv -  1) ) BIT_SET( PORTD, PD1) ; else BIT_CLEAR (PORTD , PD1);
	if (BIT_TEST(mask,inv -  2) ) BIT_SET( PORTD, PD4) ; else BIT_CLEAR (PORTD , PD4);
	if (BIT_TEST(mask,inv -  3) ) BIT_SET( PORTD, PD5) ; else BIT_CLEAR (PORTD , PD5);
	if (BIT_TEST(mask,inv -  4) ) BIT_SET( PORTD, PD6) ; else BIT_CLEAR (PORTD , PD6);
	if (BIT_TEST(mask,inv -  5) ) BIT_SET( PORTB, PB0) ; else BIT_CLEAR (PORTB , PB0);
	if (BIT_TEST(mask,inv -  6) ) BIT_SET( PORTB, PB1) ; else BIT_CLEAR (PORTB , PB1);
	if (BIT_TEST(mask,inv -  7) ) BIT_SET( PORTB, PB2) ; else BIT_CLEAR (PORTB , PB2);
	if (BIT_TEST(mask,inv -  8) ) BIT_SET( PORTB, PB3) ; else BIT_CLEAR (PORTB , PB3);
	if (BIT_TEST(mask,inv -  9) ) BIT_SET( PORTB, PB4) ; else BIT_CLEAR (PORTB , PB4);
	if (BIT_TEST(mask,inv - 10) ) BIT_SET( PORTA, PA0) ; else BIT_CLEAR (PORTA , PA0);
	if (BIT_TEST(mask,inv - 11) ) BIT_SET( PORTA, PA1) ; else BIT_CLEAR (PORTA , PA1);
	#undef inv
}

// setup hardware , timers and sleep mode
void setup()
{
	// disable analog comparator
	ACSR |= (1 << ACD);
	// disable unused modules in PRR, we are using timer1
	PRR |= (1 << PRUSI);  // disable timer/Counter1 and USI

	//PRR &= ~(1 << PRTIM1); // Ensure Timer1 is enabled

	// set led pins as output
	DDRA |= 0b00000011;				// for PA1 and PA0
	DDRB |= 0b00111111;				// for PB4 to PB0 and pb5 for mosi
	DDRD |= 0b01110011;				// for PD6, PD5, PD4, PD1 and PD0
	
	//power up mosi
	BIT_SET( PORTB, PB5);
	
	// we're on the saving bytes route
	// set hall effect sensor pin PD3 as input
	//DDRD &= ~(1 << PD3);
	
	// button
	//DDRD &= ~(1 << BUTTON);			// set as input
	PORTD |= (1 << BUTTON);			// enable internal pull-up resistor

	// Configure external interrupt for button PD2
	// Set the interrupt to trigger wake mode
	//	MCUCR |=  (1 << ISC01);
	//	MCUCR &= ~(1 << ISC01);

	//	GIMSK |= (1 << INT0);			// Enable INT0
	GIMSK |= (1 << INT0) | (1 << INT1);

	// enable external interrupt on PD3 (combine to previous)
	MCUCR |= (1 << ISC11);			// trigger on rising edge only
	MCUCR &= ~(1 << ISC10);

	
	// enable global interrupts
	sei();

	// set up timer
	setupTimer();

	// set sleep mode to one of
	set_sleep_mode(SLEEP_MODE);

}
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
int main(void) {
	
	setup();
	
	// all off
	setLEDS(0);
	
	
	while (1) {
		
		sei();

		// if power is on, and button pressed  then change mode
		
		if (isSleeping == false ) {
			
			if ( readButton() == true ) {
				
				do {
					currentEffect ++;
					currentEffect %= MAX_EFFECTS;
					
					setLEDS(0b11<<currentEffect);

					// wait to let use see leds
					_delay_ms(300);


					setLEDS(0);
					
				} while(readButton() == true);
			}
			} else {
			
			// indicate we just woke up
			setLEDS(0xfff);
			
			// woken
			isSleeping = false;
			
			_delay_ms(300);
			
			setLEDS(0);
		}
		
		// power down hall effect sensor if counter has finished
		if( powerDownCountdown-- == 0  ) {
			
			// enable sleep mode
			sleep_enable();
			
			// indicate we are going to sleep
			setLEDS(0xaa);
			
			// turn off MOSI
			BIT_CLEAR( PORTB, PB5);
			_delay_ms(50);
			
			powerDownCountdown = COUNTDOWN_LENGTH;
			
			isSleeping = true;

			// LEDS of before sleep
			setLEDS(0x0);
			
			// put CPU to sleep
			sleep_cpu();
		}
		
		// range check
		if( powerDownCountdown >COUNTDOWN_LENGTH  ){
			powerDownCountdown = COUNTDOWN_LENGTH;
		}
		
		// run sequence if hall effect was set
		if( isTriggered ) {
			
			// reset state for hall effect. moved it here so we can use a trigger to break out of an effect and not overrun
			isTriggered = false;
			
			lightLedsInSequence();
			
			// simple timer for the animated demos
			if( count == 10 ) {
				
				// change sub mode
				fillModeEffects ++;
				
				if( fillModeEffects == 4) {
					fillModeEffects = 0;
				}
				count = 0;
			}
			
			count ++;
		}
	}
}

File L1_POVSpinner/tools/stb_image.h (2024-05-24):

/* stb_image - v2.10 - public domain image loader - http://nothings.org/stb_image.h
									 no warranty implied; use at your own risk

   Do this:
	  #define STB_IMAGE_IMPLEMENTATION
   before you include this file in *one* C or C++ file to create the implementation.

   // i.e. it should look like this:
   #include ...
   #include ...
   #include ...
   #define STB_IMAGE_IMPLEMENTATION
   #include "stb_image.h"

   You can #define STBI_ASSERT(x) before the #include to avoid using assert.h.
   And #define STBI_MALLOC, STBI_REALLOC, and STBI_FREE to avoid using malloc,realloc,free


   QUICK NOTES:
	  Primarily of interest to game developers and other people who can
		  avoid problematic images and only need the trivial interface

	  JPEG baseline & progressive (12 bpc/arithmetic not supported, same as stock IJG lib)
	  PNG 1/2/4/8-bit-per-channel (16 bpc not supported)

	  TGA (not sure what subset, if a subset)
	  BMP non-1bpp, non-RLE
	  PSD (composited view only, no extra channels, 8/16 bit-per-channel)

	  GIF (*comp always reports as 4-channel)
	  HDR (radiance rgbE format)
	  PIC (Softimage PIC)
	  PNM (PPM and PGM binary only)

	  Animated GIF still needs a proper API, but here's one way to do it:
		  http://gist.github.com/urraka/685d9a6340b26b830d49

	  - decode from memory or through FILE (define STBI_NO_STDIO to remove code)
	  - decode from arbitrary I/O callbacks
	  - SIMD acceleration on x86/x64 (SSE2) and ARM (NEON)

   Full documentation under "DOCUMENTATION" below.


   Revision 2.00 release notes:

	  - Progressive JPEG is now supported.

	  - PPM and PGM binary formats are now supported, thanks to Ken Miller.

	  - x86 platforms now make use of SSE2 SIMD instructions for
		JPEG decoding, and ARM platforms can use NEON SIMD if requested.
		This work was done by Fabian "ryg" Giesen. SSE2 is used by
		default, but NEON must be enabled explicitly; see docs.

		With other JPEG optimizations included in this version, we see
		2x speedup on a JPEG on an x86 machine, and a 1.5x speedup
		on a JPEG on an ARM machine, relative to previous versions of this
		library. The same results will not obtain for all JPGs and for all
		x86/ARM machines. (Note that progressive JPEGs are significantly
		slower to decode than regular JPEGs.) This doesn't mean that this
		is the fastest JPEG decoder in the land; rather, it brings it
		closer to parity with standard libraries. If you want the fastest
		decode, look elsewhere. (See "Philosophy" section of docs below.)

		See final bullet items below for more info on SIMD.

	  - Added STBI_MALLOC, STBI_REALLOC, and STBI_FREE macros for replacing
		the memory allocator. Unlike other STBI libraries, these macros don't
		support a context parameter, so if you need to pass a context in to
		the allocator, you'll have to store it in a global or a thread-local
		variable.

	  - Split existing STBI_NO_HDR flag into two flags, STBI_NO_HDR and
		STBI_NO_LINEAR.
			STBI_NO_HDR:     suppress implementation of .hdr reader format
			STBI_NO_LINEAR:  suppress high-dynamic-range light-linear float API

	  - You can suppress implementation of any of the decoders to reduce
		your code footprint by #defining one or more of the following
		symbols before creating the implementation.

			STBI_NO_JPEG
			STBI_NO_PNG
			STBI_NO_BMP
			STBI_NO_PSD
			STBI_NO_TGA
			STBI_NO_GIF
			STBI_NO_HDR
			STBI_NO_PIC
			STBI_NO_PNM   (.ppm and .pgm)

	  - You can request *only* certain decoders and suppress all other ones
		(this will be more forward-compatible, as addition of new decoders
		doesn't require you to disable them explicitly):

			STBI_ONLY_JPEG
			STBI_ONLY_PNG
			STBI_ONLY_BMP
			STBI_ONLY_PSD
			STBI_ONLY_TGA
			STBI_ONLY_GIF
			STBI_ONLY_HDR
			STBI_ONLY_PIC
			STBI_ONLY_PNM   (.ppm and .pgm)

		 Note that you can define multiples of these, and you will get all
		 of them ("only x" and "only y" is interpreted to mean "only x&y").

	   - If you use STBI_NO_PNG (or _ONLY_ without PNG), and you still
		 want the zlib decoder to be available, #define STBI_SUPPORT_ZLIB

	  - Compilation of all SIMD code can be suppressed with
			#define STBI_NO_SIMD
		It should not be necessary to disable SIMD unless you have issues
		compiling (e.g. using an x86 compiler which doesn't support SSE
		intrinsics or that doesn't support the method used to detect
		SSE2 support at run-time), and even those can be reported as
		bugs so I can refine the built-in compile-time checking to be
		smarter.

	  - The old STBI_SIMD system which allowed installing a user-defined
		IDCT etc. has been removed. If you need this, don't upgrade. My
		assumption is that almost nobody was doing this, and those who
		were will find the built-in SIMD more satisfactory anyway.

	  - RGB values computed for JPEG images are slightly different from
		previous versions of stb_image. (This is due to using less
		integer precision in SIMD.) The C code has been adjusted so
		that the same RGB values will be computed regardless of whether
		SIMD support is available, so your app should always produce
		consistent results. But these results are slightly different from
		previous versions. (Specifically, about 3% of available YCbCr values
		will compute different RGB results from pre-1.49 versions by +-1;
		most of the deviating values are one smaller in the G channel.)

	  - If you must produce consistent results with previous versions of
		stb_image, #define STBI_JPEG_OLD and you will get the same results
		you used to; however, you will not get the SIMD speedups for
		the YCbCr-to-RGB conversion step (although you should still see
		significant JPEG speedup from the other changes).

		Please note that STBI_JPEG_OLD is a temporary feature; it will be
		removed in future versions of the library. It is only intended for
		near-term back-compatibility use.
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

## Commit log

2024-05-26 Add files via upload
    added 3mf's for case
    [L1_2024_PROD_Spinner_Sparkle.3mf]
2024-05-28 Update README.md
    Updated Flashing the board section.
2024-05-28 added eagle files for badge.
    [spin_pov_LDO.brd, spin_pov_LDO.sch]

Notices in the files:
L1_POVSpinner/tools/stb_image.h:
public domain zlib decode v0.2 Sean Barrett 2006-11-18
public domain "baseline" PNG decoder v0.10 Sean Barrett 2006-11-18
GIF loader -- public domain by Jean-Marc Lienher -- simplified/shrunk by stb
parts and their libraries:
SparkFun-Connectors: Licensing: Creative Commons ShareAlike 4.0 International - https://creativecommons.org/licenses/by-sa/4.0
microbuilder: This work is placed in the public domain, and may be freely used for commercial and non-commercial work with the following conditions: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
